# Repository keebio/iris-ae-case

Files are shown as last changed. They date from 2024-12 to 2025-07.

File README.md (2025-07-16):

# Iris AE Aluminum Keyboard Case

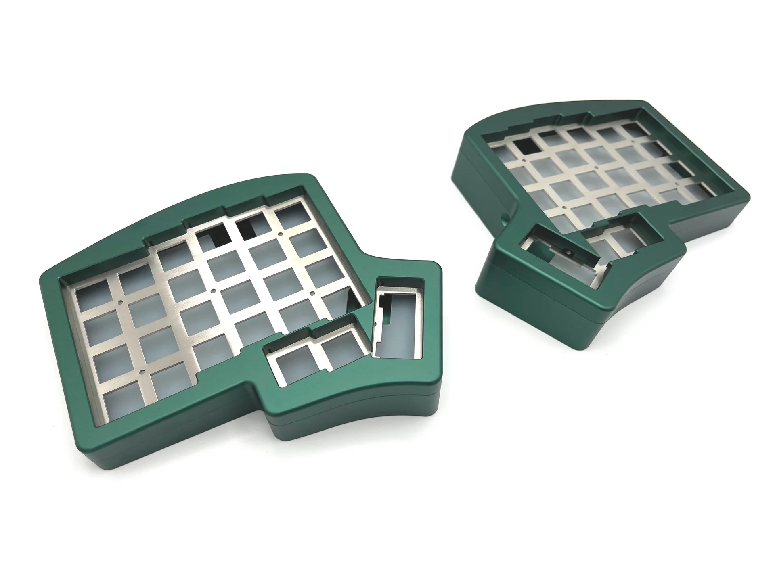
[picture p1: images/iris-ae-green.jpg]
Green Iris AE Case


With the discontinuation of the [Iris AE Aluminum Case](https://keeb.io/products/iris-ae-aluminum-case), the case files are being released for people to have their own case made.

These files are being provided as-is, and no additional support will be provided for use of them.

## Case Parts

The Iris AE case consists these pieces:

- Switch plate - 1.5mm thick
- Top Piece
- Bottom Piece
- [Silicone Tray Inserts](https://keeb.io/products/iris-aluminum-case-silicone-tray-insert)

Additional parts used:

- 8x [6mm M2 screws](https://s.click.aliexpress.com/e/_opXvJPD)
- 16x [12mm M3 screws](https://s.click.aliexpress.com/e/_opXvJPD)
- 16x O-rings - 4mm OD (Outer Diameter), 2mm ID (Inner Diameter), 1mm CS (Cross Section)
    - [AliExpress Listing for O-rings](https://s.click.aliexpress.com/e/_oEDcQlM) (Select `OD4-CS1`)
    - [AliExpress Listing for O-rings](https://s.click.aliexpress.com/e/_okIWTFc) (Select `OD 4mm ID 2mm`)
- [SKUF Feet](https://keeb.io/products/skuf-silicone-rubber-keyboard-feet)

## Fabrication

The top and bottom piece STEP files for the aluminum case can be submitted to various places. Exact details on ordering will vary depending on manufacturer.

### Example ordering with JLC CNC service

- Go to [JLCCNC](https://jlccnc.com/cnc-machining-quote)
- Upload STEP files
- Select Surface Finish (usually you will want `Bead blasting + Anodizing` with `Glossy` Color)
- Select `Yes` for Threads and upload the corresponding PDF drawing for that piece

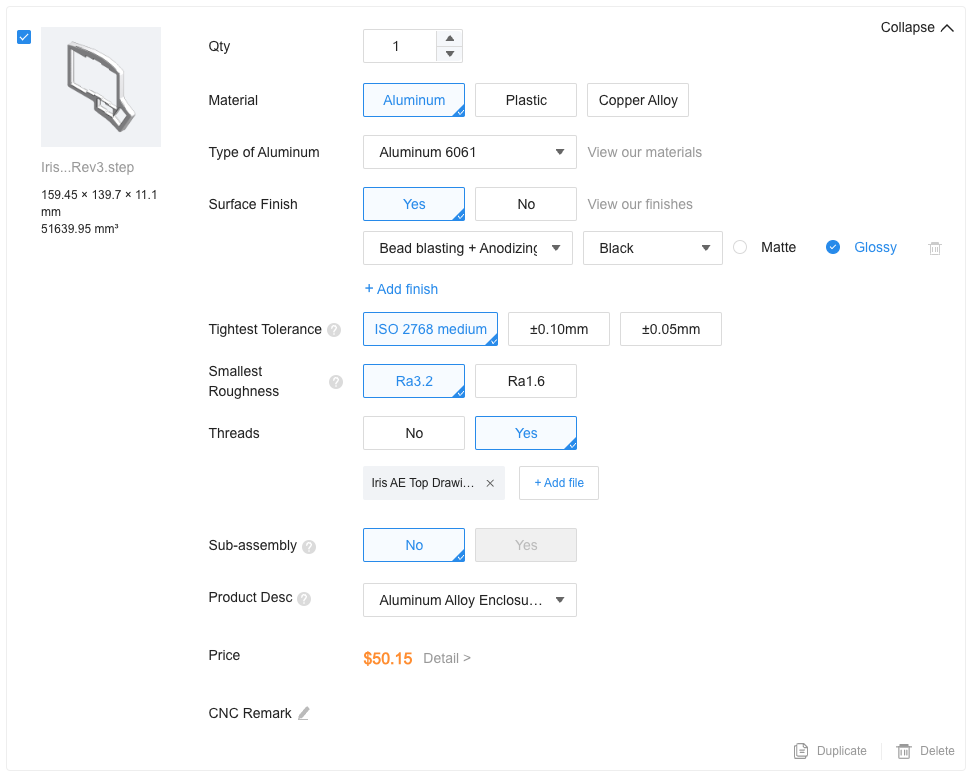
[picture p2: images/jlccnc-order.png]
JLCCNC Ordering Page


## License

These case files are released under the MIT License.

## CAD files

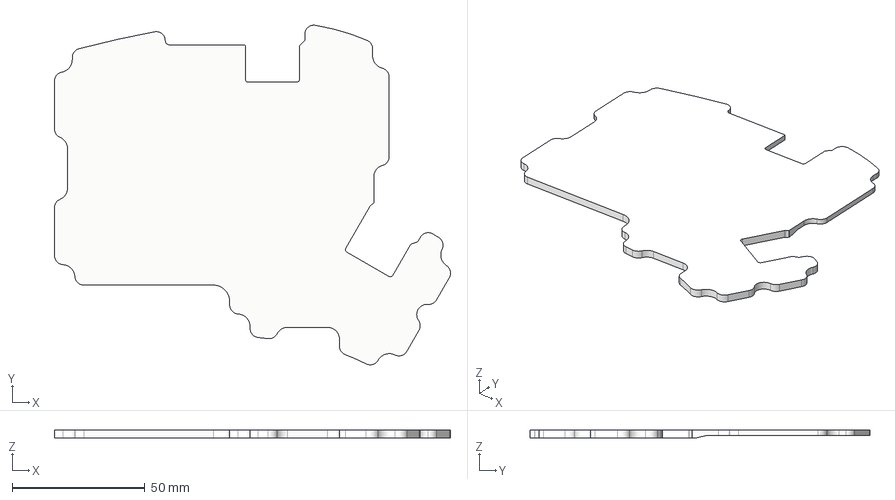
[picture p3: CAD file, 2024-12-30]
Iris AE Insert Left.step
149.2 x 127.9 x 3.16 mm

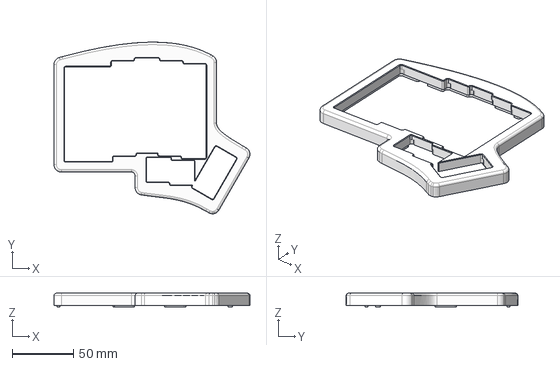
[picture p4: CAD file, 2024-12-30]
Iris AE Top Left Rev3.step
159.5 x 139.7 x 11.1 mm

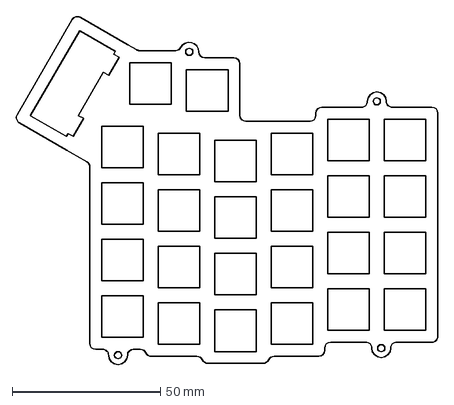
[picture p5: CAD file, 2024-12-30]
iris-ae-switch-plate.dxf
142.0 x 117.4 mm

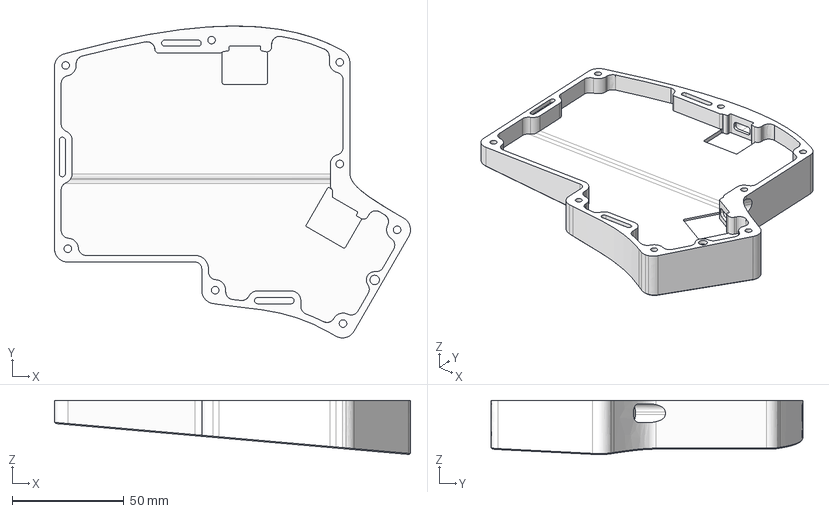
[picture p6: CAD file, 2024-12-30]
Iris AE Bottom Left Rev3.step
159.5 x 139.7 x 24.2 mm

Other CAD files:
Iris AE Insert Right.step
Iris AE Top Right Rev3.step
Iris AE Bottom Right Rev3.step

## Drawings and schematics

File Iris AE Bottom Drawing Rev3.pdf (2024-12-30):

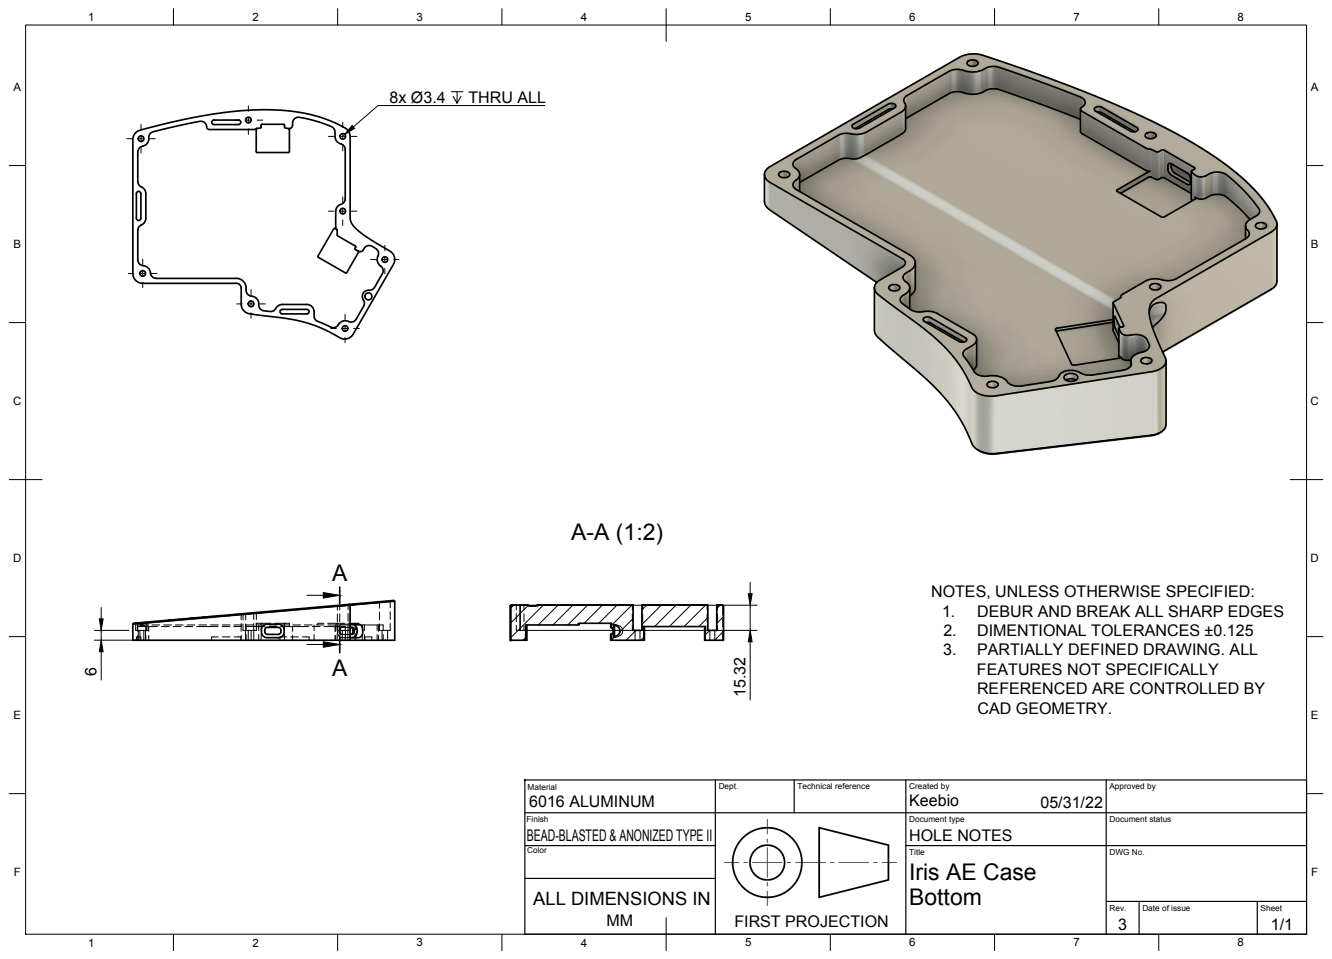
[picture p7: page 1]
THRU ALL; Rev.; Date of issue; Sheet

NOTES, UNLESS OTHERWISE SPECIFIED:
1. DEBUR AND BREAK ALL SHARP EDGES
2. DIMENTIONAL TOLERANCES ±0.125
3. PARTIALLY DEFINED DRAWING. ALL
FEATURES NOT SPECIFICALLY
REFERENCED ARE CONTROLLED BY
CAD GEOMETRY.

Material 6016 ALUMINUM | Dept. | Technical reference | Created by Keebio 05/31/22 | Approved by

Finish BEAD-BLASTED & ANONIZED TYPE II | FIRST PROJECTION | | Document type HOLE NOTES | Document status

Color | | | Title Iris AE Case Bottom | DWG No.

ALL DIMENSIONS IN

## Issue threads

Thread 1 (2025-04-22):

JLCCNC reports dxf file as damaged

NADRIGOL, 2025-04-22:
I'm new to working with these file types, so apologies if I'm overlooking something simple.

I'm trying to use JLCCNC to have these machined. The four case step files work fine, but when I upload iris-ae-switch-plate.dxf JLCCNC reports File format not support or file is damaged. They list dxf support, so I just wanted to check if anyone could confirm whether the dxf file in the github is corrupted in general, or just not working with JLCCNC.

Closed 2025-04-23.
